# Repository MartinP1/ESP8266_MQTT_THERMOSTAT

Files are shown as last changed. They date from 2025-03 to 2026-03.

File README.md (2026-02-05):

# Ein Heizkörperthermostat auf Basis eines ESP8266 und MQTT
English version 

## Projektstand
Das Projekt ist seit mehreren Jahren im operativen Einsatz.
- Temperaturmessung über 3 Sensoren, Weitergabe der Werte über MQTT
- Zuspielen der Solltemperatur über MQTT auf den ESP
- Ansteuerung von Lüftern, die den Heizkörper von unten zur Erhöhung der Heizleistung anblasen (PWM)
- Zeitplan für Änderung der Solltemperatur (realisiert über ein ioBroker Blockly Skript)
- Preferences library für Gerätekonfiguration über MQTT (kein hartverdrahteter Device Name im Quellcode mehr!)
- Fensterkontakt 
- OTA Library für den OTA-Update der Firmware

## Hardwareübersicht

- ESP basierte Hardware - es werden drei Module unterstützt.
  - D1 Mini (ESP8266) Probleme mit instabiler Spannungsversorgung (Arduino IDE "D1 Mini")
  - D1 Mini (ESP32 - seit 1.12.2023 - Arduino IDE "WEMOS D1 MINI ESP32")
  - S2 Mini (ESP32 - seit 1.12.2023 ) Neue Empfehlung!

- 12 V DC Spannungsversorgung - Ein Tisch-Netzteil von der Resterampe von [www.pollin.de](https://www.pollin.de/p/tischnetzteil-gp-1223c-12-v-2-3-a-5-5-2-1-mm-gebraucht-352200) 12V / 2,3A. 
- Danfoss Stellantrieb Thermot 230 V AC, M30x1,5 NC stromlos geschlossen [088H3220](https://store.danfoss.com/de/de/Climate-Solutions-W%C3%A4rmetechnik/Warmwasser-Fu%C3%9Fbodenheizungen/Thermische-Stellantriebe/Thermischer-Stellantrieb%2C-Thermot%2C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) ca 10 €
  - angesteuert über ein Kleinrelais
- 4 Arctic 80 mm Gehäuselüfter ([3 Pin](https://www.arctic.de/F8/ACFAN00205A) habe ich gekauft, wahrscheinlich wäre [4 Pin](https://www.arctic.de/P8-PWM/ACFAN00149A) die bessere Wahl gewesen) blasen den Heizkörper von unten an
- 3 DS 18B20 Thermosensoren von Shelly https://www.pollin.de/p/shelly-temperMQTT_PUB_DEV_PREFIXatursensor-ds18b20-591021
  - zur Messung von Zulauf- und Ablauftemperatur des Heizkörpers und der Raumtemperatur

Schaltplan

Das Prototyp-System ist stillgelegt, aktuell läuft V1 einer Kicad-Leiterplatte.
Mindestausstattung wäre ein Thermosensor für die Raumtemperatur und ein Schaltrelais für die Ansteuerung des Ventil-Stellgliedes...

## Unsortiertes

### Lüfter-Aufrüstung

Inzwischen laufen acht 80 mm Lüfter unter dem Heizkörper - Blasen in die Lücke zwischen den Platten
Dazu noch 6 50 mm Lüfter, die in die Zwischenraum zwischen der Wand und dem Heizkörper blasen

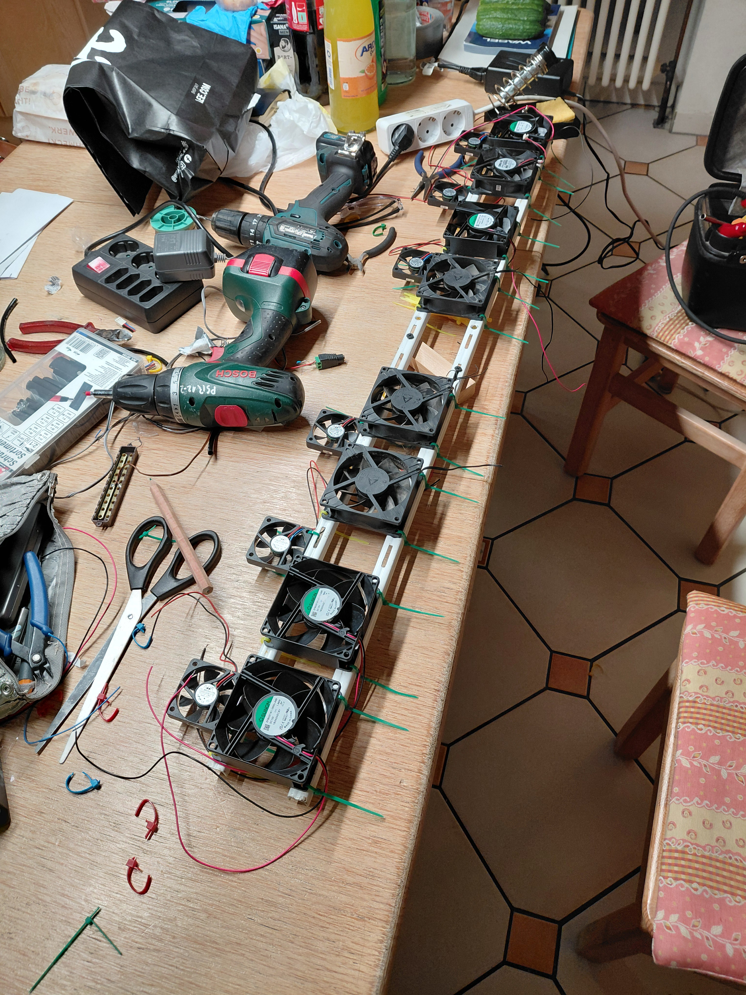
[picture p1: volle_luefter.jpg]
Volle Luefteraussstattung


Stromaufnahme ca 1,2 A, 11,1 V
PWM-Frequenz 8 kHz
Die hinzugekommenen 80mm Lüfter sind BLDC Typen. Laufen nicht unter PWM -> Glätten ist angesagt..

Ein simpler 220 uF Elko schafft das. Wird aber heiß da fehlt wohl noch eine Induktivität, um die Stromspitzen vom Eko fernzuhalten...

Rechnung 

1,2A/8000 Hz = 0,00015 As
Spannungeinbruch um 7 V (Auf 5 V) 

0,00015 As / 7 V = 22 &mu;F

220 &mu;F passt schon

Induktivität 2 A Max Vs/A - 220 &mu;H????

Schaltung aufgebaut, funktioniert.
Glättet das Signal ziemlich gut, Lüfter  laufen alle, aber die Spannungen sind deutlich geringer, als ohne Induktivität

Elektrolytkondensator 220 &mu;F, (Grabbelkiste) 
Induktivität 330 &mu;H Von Amazon
> sourcing map 5 Stück Ringkern Induktivität Kupferspule magnetische Induktivität 330uH 5A für DIY Platine

Messung: Full-Power Strom 1,16 A

| PWM | Spannung | Bemerkung |
| - | - | - |
| 255 | 10.9 V | Laut |
| 250 | 9.6 V | |
| 240 | 9.2 V | Hörbar |
| 220 | 8.3 V | |
| 200 | 7.2 V | Leise |
| 180 | 6.5 V | |
| 165 | 5.7 V | Unhörbar |
| 150 | 5.1 V | |
| Darunter | x | Verschiedene Lüfter stehen still |

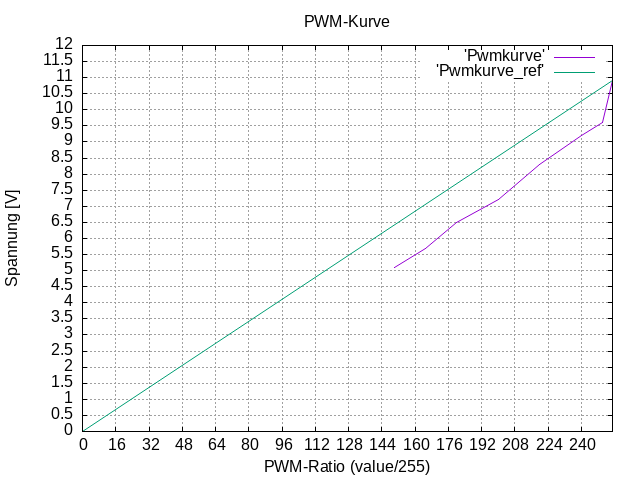
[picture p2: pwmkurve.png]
PWMKURVE


### Was fehlt noch

- Schaltplanänderung in Kicad nachpflegen, zur Stabilitätsverbesserung werden die DS18B20 jetzt mit 5 V versorgt

### Verbesserungen - was würde ich in der Serie anders machen

- 4 Pin Lüfter?
- 24 V Variante des Danfoss Stellantriebs über DCDC Wandler mit Enable-Eingang?
- Full Fan speed konfigurierbar (255 scheint zu schnell zu sein ...)
- Neues Leiterplattenlayout mit 230 V Spannungsversorgung und <del>Schaltrelais</del> Solid State Relay (für PWM) für Danfoss-Stellglied
- Migration des Projekts von Arduino-IDE auf PlatformIO

### Worklog

- JAN-2024 Start der Nutzung der Preferences Bibliothek
- MAR-2025 Diverse Code-Korrekturen bzgl. der Temperatursensoren.
- SEP-2025 
  - ASYNC_TCP issues fixed use AsyncTCP by ESP32Async 3.4.7 
  - OTA Update librariy added 
- OCT-2025             
  - Moved to espMqttClient https://github.com/bertmelis/espMqttClient/blob/main/src/espMqttClient.h
    - that fixed stability problems on esp32 single core chips
- FEB-2026 
  - changed behaviour on desired throttle speed (1.2.5)
  - p-controller on room temp diff between -hyst and 0 (1.2.6)
  - 
## Bugs 

- serial logging does not work reliable any more since 1.2.6 -> fixed by updating ESP32 board lib from 3.3.5 to 3.3.6

## Unklarheiten

Wenn man den Client an einen Mosquitto anschließt, und beim Schreiben des Mosquittos 
immer den Wert "Echoed" passieren komische Sachen. Beim MQTT-Adapter des ioBroker nicht ...

Wenn nach der Verbindungsaufnahme mit dem Broker vom Broker eine Null für den Wert kommt, 
ein Publish mit den "Werkseinstellungen" machen?

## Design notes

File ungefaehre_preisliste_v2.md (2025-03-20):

| Artikel | Stückzahl | Stückpreis |Gesamtpreis | Lieferant | 
| ---- | ---- | ---- | ---- | --- |
| Gehäuse Kemo G087N | 1 | 7,50 | 7,50 | Amazon 
| AC/DC Wandler Hi-Link 230/12/2A HLK-15M12C | 1 | ca 3 € | 3 € 
| Relais 12 V 1 Kontakt  JQC3F(T73) 12V DC  | 1 | 1 € (im 5er Pack) | 1€ | 
| Lolin S2 mini | 1 | 3,50 € |3,50 € 
| DC-DC LM2696S | 1 | 3,50 €| 3,50 € 
| Temperaturfühler DS18B20 | 3 | 3,33 € | 10 € |
| Lüfter 80 mm 12 V | 4 | 3 € | 12 € | 
| Danfoss Thermostat/Stelltrieb 230 V NC 088H3220 | 1 | 12 € | 12 €

Summe ca 50 €

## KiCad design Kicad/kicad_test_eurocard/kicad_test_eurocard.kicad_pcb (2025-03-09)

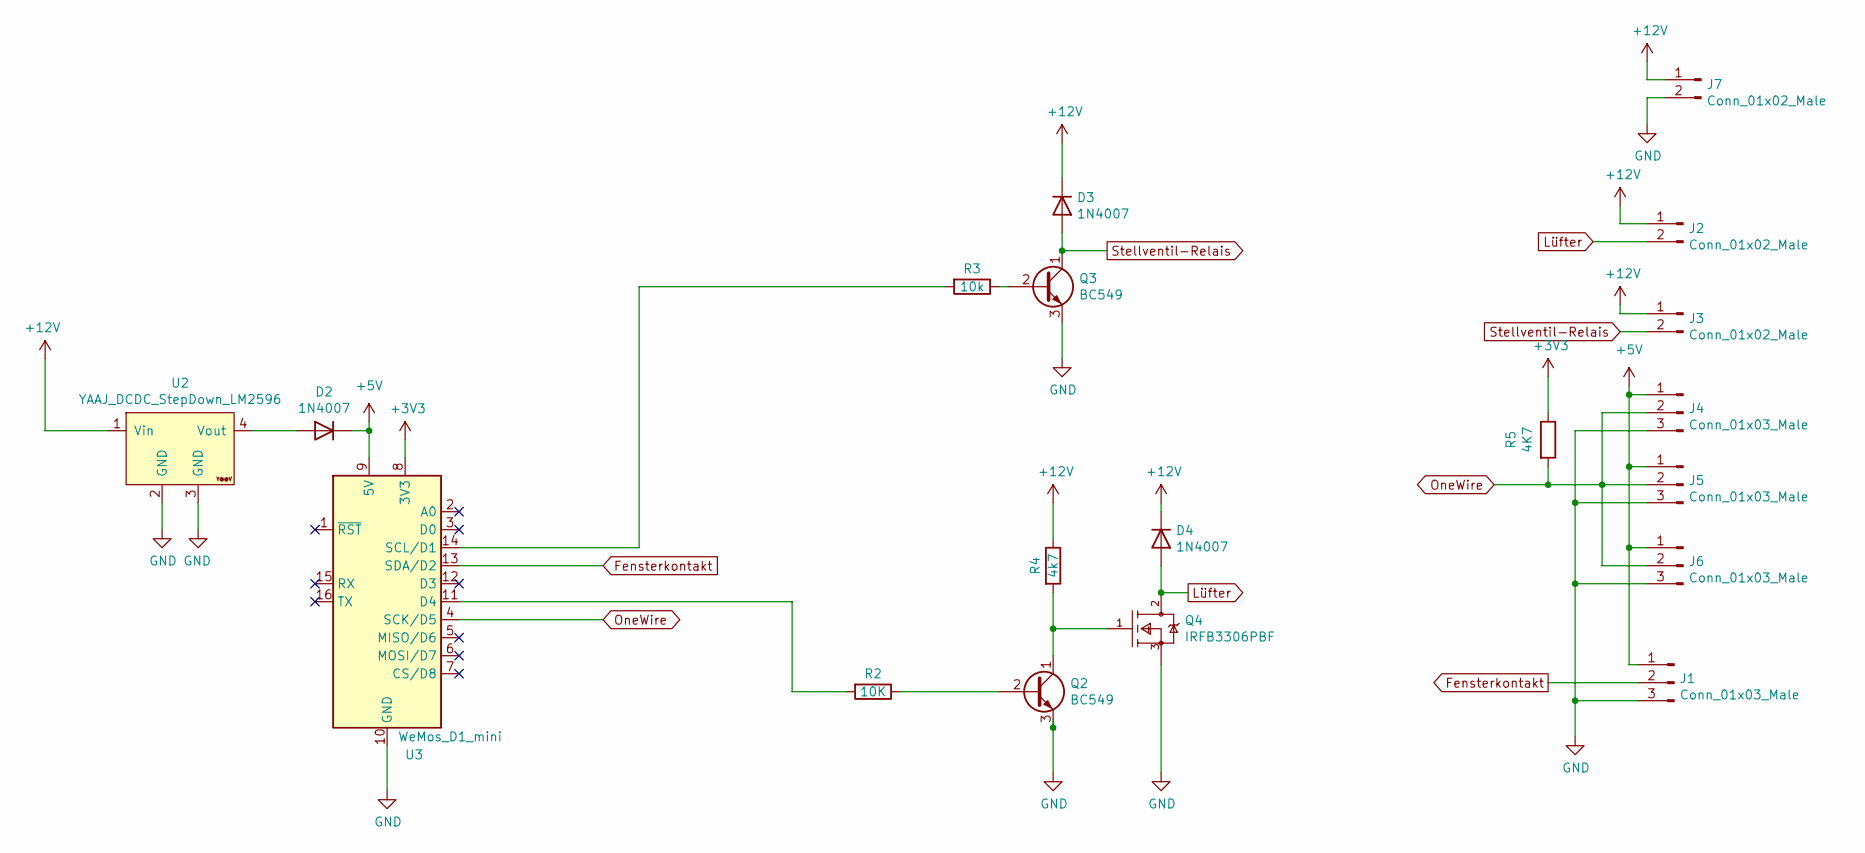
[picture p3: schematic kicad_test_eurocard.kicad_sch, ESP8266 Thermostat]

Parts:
D2, D3, D4: 1N4007; D_DO-41_SOD81_P10.16mm_Horizontal
J1, J4, J5, J6: Conn_01x03_Male; PinHeader_1x03_P2.54mm_Vertical
J2, J3, J7: Conn_01x02_Male; PinHeader_1x02_P2.54mm_Vertical
Q2, Q3: BC549; TO-92_Inline
Q4: IRFB3306PBF; Infineon_Technologies-PG-TO220-3-02_2008-904-MFG; mouser part number 942-IRFB3306PBF; digikey description MOSFET N-CH 60V 120A TO-220AB
R2: 10K; R_Axial_DIN0207_L6.3mm_D2.5mm_P10.16mm_Horizontal
R3: 10k; R_Axial_DIN0207_L6.3mm_D2.5mm_P10.16mm_Horizontal
R4: 4k7; R_Axial_DIN0207_L6.3mm_D2.5mm_P10.16mm_Horizontal
R5: 4K7; R_Axial_DIN0207_L6.3mm_D2.5mm_P10.16mm_Horizontal
U2: YAAJ_DCDC_StepDown_LM2596
U3: WeMos_D1_mini; WEMOS_D1_mini_light

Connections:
+3V3: R5.1, U3.8 (3V3)
+5V: D2.1 (K), J1.1, J4.1, J5.1, J6.1, U3.9 (5V)
+12V: D3.1 (K), D4.1 (K), J2.1, J3.1, J7.1, R4.1, U2.1 (Vin)
Fensterkontakt: J1.2, U3.13 (SDA/D2)
GND: J1.3, J4.3, J5.3, J6.3, J7.2, Q2.3 (E), Q3.3 (E), Q4.3 (S), U2.2 (GND), U2.3 (GND), U3.10 (GND)
Lüfter: D4.2 (A), J2.2, Q4.2 (D)
unnamed: D2.2 (A), U2.4 (Vout)
unnamed: Q2.2 (B), R2.1
unnamed: Q2.1 (C), Q4.1 (G), R4.2
unnamed: Q3.2 (B), R3.1
unnamed: R2.2, U3.11 (D4)
unnamed: R3.2, U3.14 (SCL/D1)
OneWire: J4.2, J5.2, J6.2, R5.2, U3.4 (SCK/D5)
Stellventil-Relais: D3.2 (A), J3.2, Q3.1 (C)

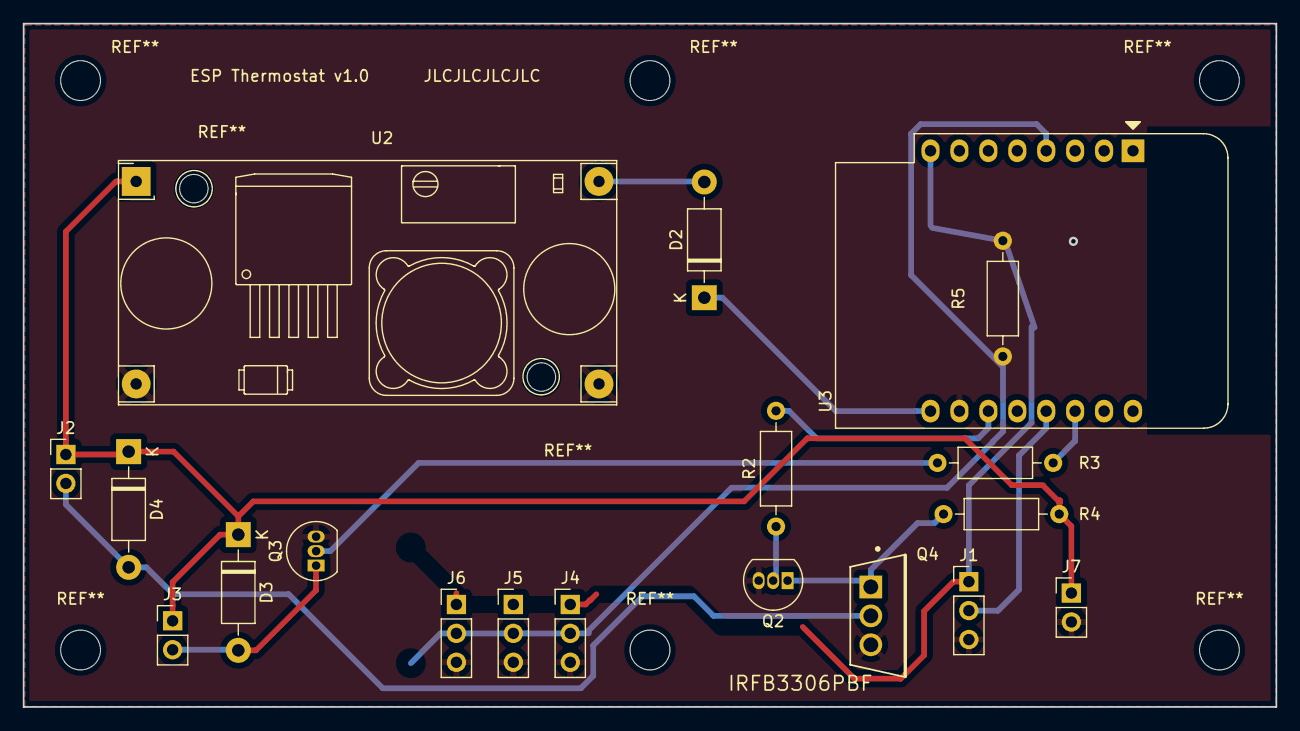
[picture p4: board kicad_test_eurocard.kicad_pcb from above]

Board: 2 copper layers, 110.0 x 60.0 mm, 19 parts (0 on the bottom side), 14 nets.

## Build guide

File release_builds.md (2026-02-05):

# Summary of used libraries etc for building releases

Scan build output copied from arduino output window to file with

```
martin@martin-D2836-S1:~/Temp$ cat Arduino-build.log | grep -i -e "using board" -e "using library" >used_libs.txt
```

Paste content of used_libs.txt to wiki article

## 1.2.4 06-OCT-2025

```
Using board 'lolin_s2_mini' from platform in folder: /home/martin/.arduino15/packages/esp32/hardware/esp32/3.3.0
Using library Preferences at version 3.3.0 in folder: /home/martin/.arduino15/packages/esp32/hardware/esp32/3.3.0/libraries/Preferences 
Using library DallasTemperature at version 4.0.5 in folder: /home/martin/Arduino/libraries/DallasTemperature 
Using library OneWire at version 2.3.8 in folder: /home/martin/Arduino/libraries/OneWire 
Using library WiFi at version 3.3.0 in folder: /home/martin/.arduino15/packages/esp32/hardware/esp32/3.3.0/libraries/WiFi 
Using library Networking at version 3.3.0 in folder: /home/martin/.arduino15/packages/esp32/hardware/esp32/3.3.0/libraries/Network 
Using library ESPmDNS at version 3.3.0 in folder: /home/martin/.arduino15/packages/esp32/hardware/esp32/3.3.0/libraries/ESPmDNS 
Using library ArduinoOTA at version 3.3.0 in folder: /home/martin/.arduino15/packages/esp32/hardware/esp32/3.3.0/libraries/ArduinoOTA 
Using library Update at version 3.3.0 in folder: /home/martin/.arduino15/packages/esp32/hardware/esp32/3.3.0/libraries/Update 
Using library espMqttClient at version 1.7.1 in folder: /home/martin/Arduino/libraries/espMqttClient-1.7.1 
Using library NetworkClientSecure at version 3.3.0 in folder: /home/martin/.arduino15/packages/esp32/hardware/esp32/3.3.0/libraries/NetworkClientSecure 
Using library Async TCP at version 3.4.9 in folder: /home/martin/Arduino/libraries/Async_TCP 
```

## 1.2.6 5-FEB-2026

```
Using board 'lolin_s2_mini' from platform in folder: /home/martin/.arduino15/packages/esp32/hardware/esp32/3.3.6
Using library Preferences at version 3.3.6 in folder: /home/martin/.arduino15/packages/esp32/hardware/esp32/3.3.6/libraries/Preferences 
Using library DallasTemperature at version 4.0.5 in folder: /home/martin/Arduino/libraries/DallasTemperature 
Using library OneWire at version 2.3.8 in folder: /home/martin/Arduino/libraries/OneWire 
Using library WiFi at version 3.3.6 in folder: /home/martin/.arduino15/packages/esp32/hardware/esp32/3.3.6/libraries/WiFi 
Using library Networking at version 3.3.6 in folder: /home/martin/.arduino15/packages/esp32/hardware/esp32/3.3.6/libraries/Network 
Using library ESPmDNS at version 3.3.6 in folder: /home/martin/.arduino15/packages/esp32/hardware/esp32/3.3.6/libraries/ESPmDNS 
Using library ArduinoOTA at version 3.3.6 in folder: /home/martin/.arduino15/packages/esp32/hardware/esp32/3.3.6/libraries/ArduinoOTA 
Using library Update at version 3.3.6 in folder: /home/martin/.arduino15/packages/esp32/hardware/esp32/3.3.6/libraries/Update 
Using library espMqttClient at version 1.7.1 in folder: /home/martin/Arduino/libraries/espMqttClient-1.7.1 
Using library NetworkClientSecure at version 3.3.6 in folder: /home/martin/.arduino15/packages/esp32/hardware/esp32/3.3.6/libraries/NetworkClientSecure 
Using library Hash at version 3.3.6 in folder: /home/martin/.arduino15/packages/esp32/hardware/esp32/3.3.6/libraries/Hash 
Using library Async TCP at version 3.4.10 in folder: /home/martin/Arduino/libraries/Async_TCP 
```

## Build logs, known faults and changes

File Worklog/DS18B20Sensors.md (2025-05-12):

# Probleme mit DS18B20 Sensoren

Die Sensoren fallen regelmäßig aus. 
Die letzte Firmware-Änderung soll die Überwachung noch einmal verbessern.
Ich werde hier mal etwas Protokoll führen, ob ein bestimmter Sensor betroffen ist, oder reihum alle Sensoren Ausfallneigung haben.
Bisher konnte ich den Fehler jeweils durch komplettes Spannungslos machen des ESP-Moduls beheben.

Die Versorgungsspannung der Sensoren habe ich schon von 3,3 auf 5 Volt angehoben.

## Protokoll Vorfälle

Seriennummern /IDs der Sensoren.
| Datum | 3C13E381F66D |  3C1E0457CBD0 |  3C610457DB22 |
|---|---|---|---|
| 10-MAY-2025 | ok | fail | ok |

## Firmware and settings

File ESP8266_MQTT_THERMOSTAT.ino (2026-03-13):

#define VERSION_NO "1.2.7 13-MAR-2026"
#include "./GLOBAL_VARS_MQTT_DS18B20.h"
#include "unspecialized_mqtt_doings.h"
#include "MqttLogging.h"
#include "desired_temp_MQTT_DS18B20.h"
#include "desired_speed_MQTT_DS18B20.h"
#include "received_temp_MQTT_DS18B20.h"
#include "fan_pwm_MQTT_DS18B20.h"
#include "window_contact_MQTT_DS18B20.h"
#include "do_calculations_MQTT_DS18B20.h"
#if USE_MQTT_BINDING_CLASS
#include "MqttBindings.h"
#endif
#if !defined(ARDUINO_D1_MINI32) && !defined(ARDUINO_LOLIN_S2_MINI) && !defined(ARDUINO_ESP8266_WEMOS_D1MINI)
#error "unsupported board type"
#error ARDUINO_BOARD
#else
#pragma message ARDUINO_BOARD is selected
#endif

#include "thermostat_preferences.h"

void onMqttConnect(bool sessionPresent) {
  //DumpFreeRAM();
  Serial.print("Connected to MQTT - IP=");
  Serial.print(WiFi.localIP());
  Serial.print("- RSSI: ");
  Serial.print(WiFi.RSSI());
  Serial.print(" dB - Session present: ");
  Serial.print(sessionPresent);
  Serial.println("StackFree: ");
  delay(200);
  // todo not necessarily QOS 2, 1 or 0 are also ok... 
#if 0
  // try to subscribe a complete tree with all leafs does nont work with bertmelis/espMqttClient
  uint16_t packetIdSub = mqttClient.subscribe((MQTT_PUB_DES_PREFIX).c_str(), 2);
  Serial.print("Subscribing desired tree at QOS2, packetId: ");
  Serial.println(packetIdSub);
#else
  uint16_t packetIdSub = mqttClient.subscribe((MQTT_PUB_DES_PREFIX MQTT_PUB_TEMP_SUFFIX).c_str(), 2);
  Serial.print("Subscribing desired temp at QoS 2, packetId: ");
  Serial.println(packetIdSub);
  #if MQTT_PUBLISH_SUBSCRIBED
  publishDesTemp(desired_temp); // must be created by mqtt broker
  #endif
  packetIdSub = mqttClient.subscribe((MQTT_PUB_DES_PREFIX MQTT_PUB_TEMPHYST_SUFFIX).c_str(), 2);
  Serial.print("Subscribing desired hyst at QoS 2, packetId: ");
  Serial.println(packetIdSub);
  #if MQTT_PUBLISH_SUBSCRIBED
  publishTempHyst(temp_hyst); // must be created by mqtt broker
  #endif
  packetIdSub = mqttClient.subscribe((MQTT_PUB_DES_PREFIX MQTT_PUB_FANTHROTTLE_SUFFIX).c_str(), 2);
  Serial.print("Subscribing max fan speed at QoS 2, packetId: ");
  Serial.println(packetIdSub);
  #if MQTT_PUBLISH_SUBSCRIBED
  publishDesSpeed(PWM_THROTTLE); //must be created by broker (?)
  #endif
#endif  
  packetIdSub = mqttClient.subscribe((MQTT_PUB_DEV_PREFIX +"/Preferences/MqttName").c_str(), 2);
  Serial.print("Subscribing desired device name, packetId: ");
  Serial.println(packetIdSub);
  packetIdSub = mqttClient.subscribe((MQTT_PUB_DEV_PREFIX +"/Preferences/Debug").c_str(), 2);
  Serial.print("Subscribing debug setting, packetId: ");
  Serial.println(packetIdSub);
  packetIdSub = mqttClient.subscribe((MQTT_PUB_DEV_PREFIX +"/Preferences/OverrideWindowsSensor").c_str(), 2);
  Serial.print("Subscribing OverrideWindowsSensor, packetId: ");
  Serial.println(packetIdSub);
  
  for (int i=0;i<numberOfDevices; i++){
    publishSensorState(i);
    is_old_valid[i]=is_valid[i]; // reporting of state fixed to one time
  }
#if 1
  char* pBuff=log_buffer;
  int written = snprintf (pBuff,119,"Thermostat %s started, %d sensors", VERSION_NO, numberOfDevices);
  int DevIdx=0;
  while (DevIdx<numberOfDevices){ 
    if (written>0){
      pBuff+=written;    
      written = snprintf (pBuff,19,", %02X%02X%02X%02X%02X%02X/%02X", 
        // statDeviceAddress[DevIdx][7], <- skipped, CRC
        statDeviceAddress[DevIdx][6], // <- MSByte of serial number
        statDeviceAddress[DevIdx][5],
        statDeviceAddress[DevIdx][4],
        statDeviceAddress[DevIdx][3],
        statDeviceAddress[DevIdx][2], 
        statDeviceAddress[DevIdx][1], // <- LSByte of serial number
        statDeviceAddress[DevIdx][0]); // <- family code set to 0x28
    } 
    else
      break;
    DevIdx++;
  }  
  MQTTLog(log_buffer);
     
#else
  MQTTLogPrintf("Thermostat started %d Thermosensors found ", numberOfDevices);
#endif  
}

#if USE_BERTMELIS
void onMqttDisconnect(espMqttClientTypes::DisconnectReason reason) {
  Serial.printf("Disconnected from MQTT: %u.\n", static_cast<uint8_t>(reason));

/*  if (WiFi.isConnected()) {
    reconnectMqtt = true;
    lastReconnect = millis();
  }*/
}

#else
void onMqttDisconnect(AsyncMqttClientDisconnectReason reason) {
  Serial.println("Disconnected from MQTT.");
  // if (WiFi.isConnected()) {
  //  mqttReconnectTimer.once(2, connectToMqtt);
  // }
  return;
  }
#endif

#if USE_BERTMELIS
void onMqttSubscribe(uint16_t packetId, const espMqttClientTypes::SubscribeReturncode* codes, size_t len) {
  Serial.println("Subscribe acknowledged.");
  Serial.print("  packetId: ");
  Serial.println(packetId);
  for (size_t i = 0; i < len; ++i) {
    Serial.print("  qos: ");
    Serial.println(static_cast<uint8_t>(codes[i]));
  }
}
#else
void onMqttSubscribe(const uint16_t& packetId, const uint8_t& qos){
  Serial.println("Subscribe acknowledged.");
  Serial.print("  packetId: ");
  Serial.println(packetId);
  Serial.print("  qos: ");
  Serial.println(qos);
}
#endif

void onMqttUnsubscribe(uint16_t packetId) {
  // Serial.println("Unsubscribe acknowledged.");
  // Serial.print("  packetSerial Id: ");
  // Serial.println(packetId);
}

void onMqttPublish(uint16_t packetId) {
  // Serial.print("Publish acknowledged.");
  // Serial.print("  packetId: ");
  // Serial.println(packetId);
}

#if USE_BERTMELIS 
void onMqttMessage(const espMqttClientTypes::MessageProperties& properties, const char* topic, const uint8_t* payload, size_t len, size_t index, size_t total) {
#else
void onMqttMessage(char* topic, char* payload, AsyncMqttClientMessageProperties properties, size_t len, size_t index, size_t total) {
#endif
  char buffer[50];
  if (len>=50)
    len=49;
  for (int i=0;i<len;i++){
    buffer [i] = payload[i];   
  buffer[len]='\0';
  }
  Serial.print("Message received, len=");
  Serial.print(buffer);
  /// Distinguish pathpayload
  testPreferences(buffer, topic);
  testDesiredTemperature(buffer, topic);  
  testDesiredTempHyst(buffer, topic);
  testDesiredFanspeed(buffer,topic);
#if USE_MQTT_BINDING_CLASS
  tempHystNode.TestReceived(topic, buffer);
#endif

}






#if 0 
/* some watchdog settings */
#include "soc/rtc_wdt.h"
void doWatchdogSettings(){
  rtc_wdt_protect_off();
  rtc_wdt_disable();
}


#include "soc/timer_group_struct.h"
#include "soc/timer_group_reg.h"

void doWatchdogSettings(){
  TIMERG1.wdtwprotect = TIMG_WDT_WKEY_VALUE; // Unlock timer config.
  TIMERG1.wdtfeed = 1; // Reset feed count.
  TIMERG1.wdtconfig0.en = 0; // Disable timer.
  TIMERG1.wdtwprotect = 0; // Lock timer config.

  TIMERG0.wdtwprotect = TIMG_WDT_WKEY_VALUE;
  TIMERG0.wdtfeed = 1;
  TIMERG0.wdtconfig0.en = 0;
  TIMERG0.wdtwprotect = 0;
}  
/* END: some hardware watchdog settings */
#endif
//SET_LOOP_TASK_STACK_SIZE(16 * 1024);  // 16KB (default 8 kB)

void setup() {
  // not working stays on 9600 baud ...Serial.begin(115200);
  Serial.begin();
  delay(4000);
  yield();
  Serial.println("*** setup ***");
  sensors.begin();
  // doWatchdog();
  // delay(4000); // give some time to startup comms 
  // Serial.println("after sensors.begin()");
  yield();
  getPreferences();
  //setMQTTBindings();
#if defined(ARDUINO_D1_MINI32) || defined(ARDUINO_LOLIN_S2_MINI)
  // ledcSetup(0, 8000, 8); // pwm#, freq, resolution(bits)
  // ledcAttachPin(pwmGpio, 0);
  ledcAttachChannel(pwmGpio, 8000, 8, 0);
#endif
#if defined(ARDUINO_ESP8266_WEMOS_D1MINI)
  pinMode(pwmGpio, OUTPUT);
  analogWriteFreq(8000);
  analogWrite(pwmGpio,255); // raw write off!
#endif  
  pinMode(valveGpio, OUTPUT);
  pinMode(windowContact, INPUT_PULLUP); 
  pinMode(oneWireBus, INPUT_PULLUP);
#if defined(ARDUINO_D1_MINI32) || defined(ARDUINO_LOLIN_S2_MINI)
  WiFi.onEvent(onWifiConnect,WiFiEvent_t::ARDUINO_EVENT_WIFI_STA_GOT_IP);
  WiFi.onEvent(onWifiDisconnect,WiFiEvent_t::ARDUINO_EVENT_WIFI_STA_DISCONNECTED);
  yield();
  // doWatchdog();
#else  
  wifiConnectHandler = WiFi.onStationModeGotIP(onWifiConnect);
  wifiDisconnectHandler = WiFi.onStationModeDisconnected(onWifiDisconnect);
#endif

  mqttClient.onConnect(onMqttConnect);
  mqttClient.onDisconnect(onMqttDisconnect);
  mqttClient.onSubscribe(onMqttSubscribe);
  mqttClient.onUnsubscribe(onMqttUnsubscribe);
  mqttClient.onPublish(onMqttPublish);
   mqttClient.onMessage(onMqttMessage);
  mqttClient.setServer(MQTT_HOST, MQTT_PORT);
  yield();
  
  // mqttClient.setKeepAlive(30);
  // If your broker requires authentication (username and password), set them below
  //mqttClient.setCredentials("REPlACE_WITH_YOUR_USE92:de:dc:42:f3:f8R", "REPLACE_WITH_YOUR_PASSWORD");
  // doWatchdog();
  Serial.println("issue connectToWifi()");
  connectToWifi();
  initTemperatureSensors();
  previousMillis = millis(); // avoid initial overrun in loop
#if OTA_UPDATES
  // Same as MQTT device name
  ArduinoOTA.setHostname(MQTT_PUB_DEV_PREFIX.c_str());
  // from secret.h
  ArduinoOTA.setPassword(OTA_PASSWORD); 
  yield();
  ArduinoOTA.begin(); 
  yield();
#endif
  Serial.println("setup() finished");
}


uint8_t lastPwm=0; 

void SelftestPwm(){
   if (lastPwm != PWM_THROTTLE) {
    lastPwm = PWM_THROTTLE;
    setSpeed(PWM_THROTTLE);
    Serial.print("set PWM to ");
    Serial.println(PWM_THROTTLE);
   }

}


unsigned short usWifiDown=12;
void loop() {
  unsigned long currentMillis = millis();
  yield();
  if (uiDebug == 1) {
    SelftestPwm();
    return;
  }
#if OTA_UPDATES
  yield();
  ArduinoOTA.handle();
  yield();
#endif
  // Every X number of seconds (interval = 10 seconds) 
  // it publishes a new MQTT message
  if (currentMillis - previousMillis >= interval) {
    // Save the last time a new reading was published
    previousMillis = currentMillis;
    // New temperature readings
    if (!wifiStatus()) return; // checks MQTT and wifi up, if not, do not try do do anything ...
    // wifiStatus();
    GetWindowState(); // stored in global variable 
    yield();


    getTemperatures();
    yield();

    runTempControl();
#if 1
// try it again ... does not help ...
    if (WiFi.isConnected() && mqttClient.connected())
    {
      usWifiDown=12;  // 2 minutes @ 10 sec run interval
    }
    else
    {
      usWifiDown--;
      Serial.print(" Wifi Error count down ");
      Serial.println(usWifiDown);
      if (usWifiDown==0) // 2 Minutes expired
        ESP.restart();
    }
#endif    
  }
 
}

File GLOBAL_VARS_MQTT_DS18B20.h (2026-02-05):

/* Martin Praekelt
MQTT Thermostat with D1 Mini Board (ESP8266)

based on below Work of Rui Santos 

28-FEB-2023 published at gitlab



*/




/*
  Rui Santos   
  Complete project details at https://RandomNerdTutorials.com/esp8266-nodemcu-mqtt-publish-ds18b20-arduino/
  
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
  The above copyright notice and this permission notice shall be included in all
  copies or substantial portions of the Software.
*/

// helper to use VSCODE - arduino ide shall determine board on the "right way"
#if !defined(ARDUINO_D1_MINI32) && !defined(ARDUINO_LOLIN_S2_MINI) && !defined(ARDUINO_ESP8266_WEMOS_D1MINI) 
#define ARDUINO_LOLIN_S2_MINI
#endif
#ifdef ARDUINO_LOLIN_S2_MINI
#define OTA_UPDATES 1
#else
#define OTA_UPDATES 0
#endif
#include <Preferences.h>
#include <DallasTemperature.h>
#ifdef ARDUINO_ESP8266_WEMOS_D1MINI
#include <ESP8266WiFi.h>
#include <LibPrintf.h>
#else
#include <WiFi.h>
#if OTA_UPDATES
#include <ESPmDNS.h>
#include <WiFiUdp.h>
#include <ArduinoOTA.h>
#endif
#endif
// #include <Ticker.h>
// #define ASYNC_MQTT_DEBUG_PORT               Serial
// #define _ASYNC_MQTT_LOGLEVEL_               1
#define USE_BERTMELIS 1
#include <espMqttClient.h> // https://github.com/bertmelis/espMqttClient/blob/main/examples/simple-esp32/simple-esp32.ino
// #include <AsyncMqttClient.h>
// #include <AsyncMqtt_Generic.h>
// #include <AsyncMQTT_ESP32.h>

// set to 1 if deployed to real target
#define SERIAL_TRACE 1

//<<<<<<< HEAD
// includes WLAN credential define

//#define WIFI_SSID "blaba_ssid"
//#define WIFI_PASSWORD "blabla_password"

#include "secret.h"

#define MIN_VORLAUF_FOR_FAN 28.0
#define MQTT_RECEIVE_ECHO 0
#define MQTT_IOB 1
#define MQTT_PUBLISH_SUBSCRIBED 0
// add postfix ..._PSET ti defines that shall be moved to NV-Preset
#if MQTT_IOB
#define MQTT_HOST IPAddress(192, 168, 2, 201)
#define MQTT_PORT 1888
#else
#define MQTT_HOST IPAddress(192, 168, 2, 196)
#define MQTT_PORT 1883
#endif
// Temperature MQTT Topics
// #define MQTT_PUB_DEV_PREFIX   "thermostat"
#define MQTT_PUB_DEV_PREFIX_PSET   "test_thermostat"
String MQTT_PUB_DEV_PREFIX(MQTT_PUB_DEV_PREFIX_PSET);

#define MQTT_PUB_TEMP_PREFIX MQTT_PUB_DEV_PREFIX + "/sensors/"
#define MQTT_PUB_TEMP_SUFFIX "/temperature"
#define MQTT_PUB_TEMPHYST_SUFFIX "/temp_hyst"
#define MQTT_PUB_TEMP_SENAV_SUFFIX "/available"

#define MQTT_PUB_ACTOR_PREFIX MQTT_PUB_DEV_PREFIX + "/actors"
#define MQTT_PUB_DES_PREFIX MQTT_PUB_DEV_PREFIX + "/desired"

#define MQTT_PUB_FANTHROTTLE_SUFFIX "/throttle_fanspeed"
#define MQTT_PUB_FANACT_SUFFIX "/actual_fanspeed"

#define MQTT_PUB_VALVE_SUFFIX "/valve"
// GPIO where the DS18B20 is connected to (16 not working, 14 and 4 tested ok...)


#ifdef ARDUINO_LOLIN_S2_MINI
const int oneWireBus = 7; 
// pwm output
const int pwmGpio = 16;          
// valve MQTT_PUB_DES_PREFI
const int valveGpio = 35;
// window contact
const int windowContact = 33;
#endif
#ifdef ARDUINO_D1_MINI32
const int oneWireBus = 18; 
// pwm output
const int pwmGpio = 16;          
// valve 
const int valveGpio = 22;
// window contact
const int windowContact = 21;
#endif
#ifdef ARDUINO_ESP8266_WEMOS_D1MINI
const int oneWireBus = 14; 
// pwm output
const int pwmGpio = 2;          
// valve 
const int valveGpio = 5;
// window contact
const int windowContact = 4;
#endif

OneWire oneWire(oneWireBus);

DallasTemperature sensors(&oneWire);
// Temperature value

#define MAX_NUMBER_OF_TEMP_DEVICES 3
float desired_temp = 21.7;
float temp_hyst = 0.15; // +/- 0.15 °C difference to desired_temp allowed

#define PWM_OFF 0

#define PWM_FULL 255

uint8_t PWM_THROTTLE=70;

uint8_t pwmActual;
bool ventState;
uint8_t uiDebug=0;
uint8_t uiWifiDisconnects=0;
uint8_t uiWifiDisconnectsOld=0;
// global variable for MQTT commsWiFiEventHandler

#if USE_BERTMELIS
espMqttClient mqttClient;
#else
AsyncMqttClient mqttClient;
#endif
#if USE_MQTT_BINDING_CLASS
#include <MQTTLeafNode.h>
#endif
// Ticker mqttReconnectTimer;
#ifdef ARDUINO_ESP8266_WEMOS_D1MINI
WiFiEventHandler wifiConnectHandler;
WiFiEventHandler wifiDisconnectHandler;
#endif
// Ticker wifiReconnectTimer;

unsigned long previousMillis = 0;   // Stores last time temperature was published
const long interval = 10000;        // Interval at which to publish sensor readings and do thermostate calculations


/// necessary function prototypes

// module received_temp
void publishSensorState(int iSensId);

#if USE_MQTT_BINDING_CLASS
CMQTTLeafNode tempHystNode;
#endif

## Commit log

2023-02-28 pwm eingebaut
2023-03-11 regler angefangen und kicad
2023-03-16 fan throttle hysteresis
2023-03-16 fan throttle linear regulation
2023-03-24 logging printf
2023-05-23 Kicad Schematics
2023-11-30 ESP32 + VSCode
    ESP32 Anpassungen und Wechsel auf VSCode
2023-12-01 D1 MINI, D1_MINI32 and S2_MINI supported
    Adaptations for three different boards now
2023-12-04 Board Type defines revised
    Board type logging in build process
2023-12-05 other board
2024-05-20 Build works again!
    With Arduino IDE
2024-06-12 fixed preferences and pwm
2024-06-13 PWM
    PWM Testing (not working at all)
2024-06-17 wifi mqtt reconnect
    wifi and mqtt reconnect moved from timer to loop()
2025-03-09 Download code options
    Load binary to chip from a drifferent server beside Desktop PC, to avoid wired USB connection to Desktop PC
2025-03-09 Kicad included
    [kicad_test_eurocard-B_Cu.gbr, kicad_test_eurocard-B_Mask.gbr, kicad_test_eurocard-Edge_Cuts.gbr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]
2025-03-11 intermediat not working state
    [ESP8266_MQTT_THERMOSTAT.ino, received_temp_MQTT_DS18B20.h]
2025-03-11 DS18B20 diagnostics added
    Hopefully provides hints whether onewire library is defiective or one of the sensor is faulty...
2025-03-13 english readme and temperature logging
2025-03-16 sensorstatus
    Sensorstatus
2025-05-09 sensor scanning improved
2025-09-30 Readme und Stability
2025-09-30 More changes, but no better startup stability
    [ESP8266_MQTT_THERMOSTAT.ino, received_temp_MQTT_DS18B20.h]
2025-10-02 Wakeup problems fixed
    connectToWifi in too short sequence between setup() and loop()
    [ESP8266_MQTT_THERMOSTAT.ino, GLOBAL_VARS_MQTT_DS18B20.h, received_temp_MQTT_DS18B20.h]
2025-10-03 Zwischenstand!
    Window Sensor MQTT and startup stability experiments.
    [ESP8266_MQTT_THERMOSTAT.ino, GLOBAL_VARS_MQTT_DS18B20.h]
2026-02-05 Fan-Steuerung mit P-Regler
2026-02-05 Gnuplot PWM vs Voltage
